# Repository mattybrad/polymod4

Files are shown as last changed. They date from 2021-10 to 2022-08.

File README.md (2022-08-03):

# PolyMod 4

A polyphonic digital synthesizer which can be patched like an analog modular synth.

Current setup is C++ code running on an Electrosmith Daisy board (with built-in DAC), on a PCB which includes potentiometers, buttons, LEDs, and circuitry to detect connections between output and input sockets.

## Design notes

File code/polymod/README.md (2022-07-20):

# test1

## Author

<!-- Insert Your Name Here -->

## Description

<!-- Describe your example here -->

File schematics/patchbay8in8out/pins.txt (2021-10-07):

Pins required to connect microcontroller (Teensy, Arduino, etc) to patchbay board:

(IN ORDER, TOP TO BOTTOM)
VCC (3.3V/5V)
Output data (arduino 2)
Output clock (arduino 3, etc)
Output latch
Input load
Input clock
Input clock enable
Input data (...arduino 8)
GND

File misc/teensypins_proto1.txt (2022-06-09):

Pins for PCB prototype 1.
Pins in round brackets are required by audio board.

0       MIDI input (6N138)
1       Utility 595 data
2       Patching 595 data
3       Patching 595 clock
4       Patching 595 latch
5       Utility 595 clock
6       Utility 595 latch
7       (Audio data) (N.B. ALSO PT8211 DIN)
8       (Audio data)
9       Patching 165 load
10      Patching 165 clock
11      Patching 165 clock enable
12      Patching 165 data

13      Basic LED
14  A0  4051 #1
15  A1  4051 #2
16  A2  4051 #3
17  A3  4051 #4
18  A4  (Audio control) (Display SDA)
19  A5  (Audio control) (Display SCL)
20  A6  (Audio data) (N.B. ALSO PT8211 WS)
21  A7  (Audio data) (N.B. ALSO PT8211 BCK)
22  A8  4051 #5 (buttons etc)
23  A9  (Audio data)

(Pins 24 onwards are Teensy 4.1 only, hence just for debugging/experimental stuff)
24  A10 MIDI output
25  A11 
26  A12 
27  A13 
28      
29      
30      
31      
32      

33      
34      
35      
36      
37      
38  A14 
39  A15 
40  A16 
41  A17 

This design doesn't make optimal use of all the pins, but is a good compromise to make coding a bit easier. I'm using two separate chains of 595s so that patching (which is already complex) doesn't get any harder. LEDs are driven by 595s, which is not ideal but just makes things easy rather than learning about LED driver ICs just for a prototype. Tactile buttons are running through a 5th 4051 because I'm already addressing the 4051 group so it means I don't have to add more 165s. 4051s are addressed by the 595s because of lack of pins. One pin was spare, hence using pin 13 as LED for debugging etc. A Teensy 4.1 can be connected for extra pins. I've included pin info for the PT8211 because this might be the chip in the final design rather than an audio adaptor board. Happily, the PT8211 only uses a subset of the audio shield's pins, so I can try swapping out the boards on the prototype without changing the PCB. LATEST UPDATE actually probably using PCM5102 instead. Not totally sure which pins it uses yet.

A more optimal design might be something like:

0       MIDI input (6N138)
1       LED driver?
2       595 data
3       595 clock
4       595 latch
5       LED driver?
6       LED driver?
7       (Audio data)
8       (Audio data)
9       165 load
10      165 clock
11      165 clock enable
12      165 data

13      LED driver?
14  A0  4051 #1
15  A1  4051 #2
16  A2  4051 #3
17  A3  4051 #4
18  A4  (Audio control)
19  A5  (Audio control)
20  A6  (Audio data)
21  A7  (Audio data)
22  A8  LED driver?
23  A9  (Audio data)

24  A10 
25  A11 
26  A12 
27  A13 
28      
29      
30      
31      
32      

33      
34      
35      
36      
37      
38  A14 
39  A15 
40  A16 
41  A17 

To drive LEDs and an OLED display, we could either route the 4051 outputs into an extra 4051, or just switch to Teensy 4.1. Other future considerations include CV in/out and SD card stuff.

PROBABLY ALLOW 4.1 TO BE CONNECTED TO PCB IF BOTH ARE INTERACHANGEABLE

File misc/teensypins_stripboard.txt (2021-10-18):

Pins for interim stripboard prototype.
Pins in round brackets are required by audio board.
Pins in square brackets likely to change for next version.

0       MIDI input
1
2       Patching 595 data
3       Patching 595 clock
4       Patching 595 latch
5
6
7       (Audio data)
8       (Audio data)
9       Patching 165 load
10      Patching 165 clock
11      Patching 165 clock enable
12      Patching 165 data

13
14  A0  [Pot 0]
15  A1  [Pot 1]
16  A2  [Pot 2]
17  A3  [Pot 3]
18  A4  (Audio control)
19  A5  (Audio control)
20  A6  (Audio data)
21  A7  (Audio data)
22  A8
23  A9  (Audio data)

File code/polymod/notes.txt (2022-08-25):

Have now got a working system, in mono at least.
A few next steps:
        Tidy up the source code, making it nicer to define sockets/modules
        Better pseudo connection system
    Also make pot definitions part of same slickening process
        InVal and OutVal might be unnecessary, could just use Val?
        Centralise sample rate, don't just hardcode 48000 each time
    Add some error catching stuff to prevent compilation of bad configurations
        Add logical pin ordering (0 at top, 31 at bottom)
    Optimise delays - system tick stuff is blocking? and delayMS is too coarse (callback system?)
    Smooth analog controls (sounds too "steppy")
        Add LFO module to help test filters etc
        Add polyphony (!!!)
    Add RPS module
    Add CPU monitoring
    Stress-test the code
    Fade in connections
        Fix bug where MIDI triggers on note off rather than note on sometimes
        Add better MIDI note handling, note off, note timestamps, etc
    Why does whole thing crash when filter receives LFO signal?!
    Values should default to zero (or some defined value) when not connected
    Bit crusher is doing something weird where it somehow removes polyphony from signal chain?!
    Plan/write patch save system (QSPI? SD? External EEPROM?)
    Try setting up some nice patches, e.g. krell, filtered noise
    Think of some cool poly-specific modules, e.g. harmoniser

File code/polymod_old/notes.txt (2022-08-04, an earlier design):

complex (proper?) way to do ordering:

on new connection/disconnection:

start at main output socket, give orderNum 0
list all source sockets
for each 0 source:
    give orderNum 1
    for each source:
        give orderNum 2

        etc

now give modules an order
for each module, scan all sockets to find highest orderNum
process all modules in descending orderNum order (highest first, ending with IO module)
(except IO module also has audio input! which might be the first thing in chain! oh no!)

---

maybe better to process sockets instead of modules
works as above but without needing to assign orderNums to modules
but will it work in practice..?
e.g.
square wave through filter, filter modulated by lfo:
    output 0
    filter out 1
    filter mod 2
    lfo out 3
    filter in 2
    square wave out 3

    so...

    process lfo out, osc.process()
    process square wave out, osc.process()
    process filter mod, out=lfo in
    process filter in, out=square in
    process filter out, set freq, filter.process(filter in)
    process output, out=filter in

or...
two vcos into a mixer
    output 0
    mixer out 1
    mixer in A 2
    mixer in B 2
    vco A out 3
    vco B out 3

    so...

    process vcos
    mixer ins pass through
    mixer out = sum of mixer ins

--------

might need to rewrite things with above in mind
need to be able to process sockets rather than modules
are modules even necessary, other than to keep things organised?
so, something like...
init modules
add pseudoConnections between input/output sockets within modules
make some physical connections
a connected input socket should have pointer to its source output socket
and/or a connected output socket should have a pointer to its destination input socket
(sockets generally become more complex/active classes)
start at IO output
figure out processing output order
process all sockets in order
this means that socket class will need a process() function
this should probably be defined in the module class, as a pointer?
so, in vco init, sockets[0].processFunction = &processSquareOut (?)
(some worries here about interdependent sockets, but can't quite think of a good problematic example)
output socket process will be something daisySP-ish, referencing various bits of a module
input socket process will be basically set socket outVal to value of source pointer
(hopefully don't need to redefine this behaviour for each input socket)

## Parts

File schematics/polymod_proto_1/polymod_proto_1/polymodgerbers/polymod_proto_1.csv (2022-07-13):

Comment | Designator | Footprint | LCSC
Device_Audio_Electrosmith_Daisy_Seed_Rev4 | A1 | Device_Audio_Electrosmith_Daisy_Seed:Device_Audio_Electrosmith_Daisy_Seed
470uF | C1 | Capacitor_THT:CP_Radial_D6.3mm_P2.50mm
1N4148 | D1 | Diode_SMD:D_SOD-123 | C81598
LED | D2,D3,D4,D5,D6 | LED_THT:LED_D5.0mm
1N4148 | D7,D8,D9,D10,D11,D12,D13,D14,D15,D16,D17,D18,D19,D20,D21,D22,D23,D24,D25,D26,D27,D28,D29,D30,D31,D32,D33,D34,D35,D36,D37,D38 | polymodcustom:Nexperia_CFP3_SOD-123W | C81598
MountingHole | H1,H2,H3,H4 | MountingHole:MountingHole_3.2mm_M3
Conn_01x02_Male | J1,J3 | Connector_PinHeader_2.54mm:PinHeader_1x02_P2.54mm_Vertical
Conn_01x03_Male | J2,J14 | Connector_PinHeader_2.54mm:PinHeader_1x03_P2.54mm_Vertical
Barrel_Jack | J4 | Connector_PinHeader_2.54mm:PinHeader_1x02_P2.54mm_Vertical
Conn_01x08_Male | J6,J7,J8,J9,J10,J11,J12,J13 | Connector_PinSocket_2.54mm:PinSocket_1x08_P2.54mm_Vertical
Jumper_2_Open | JP1 | Connector_PinHeader_2.54mm:PinHeader_1x02_P2.54mm_Vertical
220 | R1,R4,R5 | polymodcustom:R_0805_2012Metric | C17557
10K | R11,R12,R13,R14,R15,R16,R17,R18,R19,R20,R21,R22,R23,R24,R25,R26,R27,R28,R29,R30,R31,R32,R33,R34,R35,R36,R37,R38,R39,R40,R41,R42 | polymodcustom:R_0805_2012Metric | C17414
10k | R2 | polymodcustom:R_0805_2012Metric | C17414
470 | R3 | polymodcustom:R_0805_2012Metric | C17710
680R | R6,R7,R8,R9,R10 | polymodcustom:R_0805_2012Metric | C17798
R_Potentiometer | RV1,RV2,RV3,RV4,RV5,RV6,RV7,RV8,RV9,RV10,RV11,RV12,RV13,RV14,RV15,RV16 | polymodcustom:Potentiometer_Alps_RK09K_Single_Vertical
SW_Push | SW1,SW2,SW3,SW4 | polymodcustom:SW_PUSH-12mm
6N138 | U1 | Package_DIP:DIP-8_W7.62mm_Socket
74HC595 | U2,U5,U8,U9,U10 | Package_SO:SOIC-16_3.9x9.9mm_P1.27mm | C5947
74LS165 | U3,U6,U11,U12,U13 | Package_SO:SOIC-16_3.9x9.9mm_P1.27mm | C5613
4051 | U4,U7 | Package_SO:SOIC-16_3.9x9.9mm_P1.27mm | C21379

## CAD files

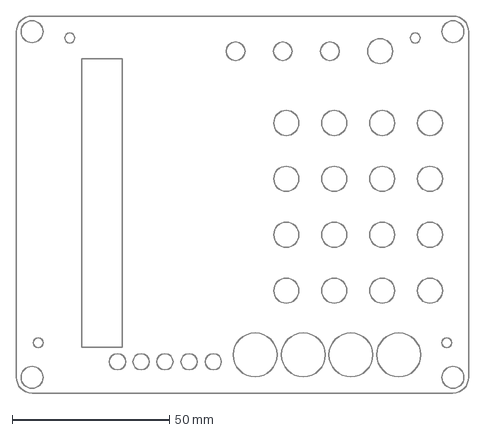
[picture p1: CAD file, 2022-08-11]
misc/lidcuts.svg.dxf
144.0 x 120.0 mm

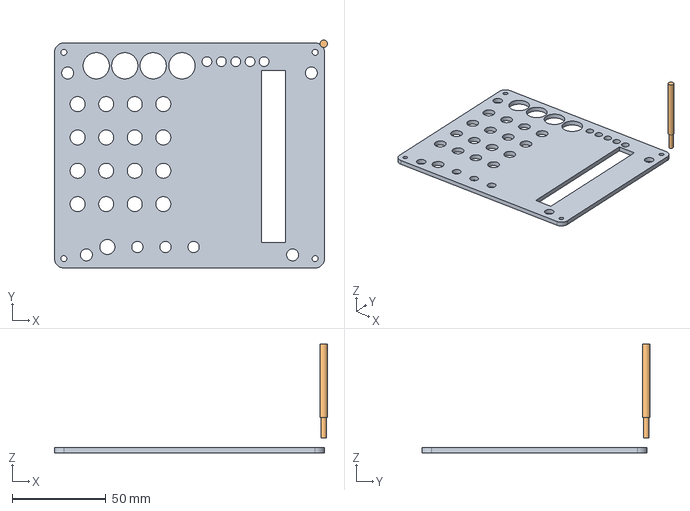
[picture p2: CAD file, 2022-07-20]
misc/morelidcutsedgeonly.FCStd
145.6 x 121.6 x 58.0 mm
CutTool

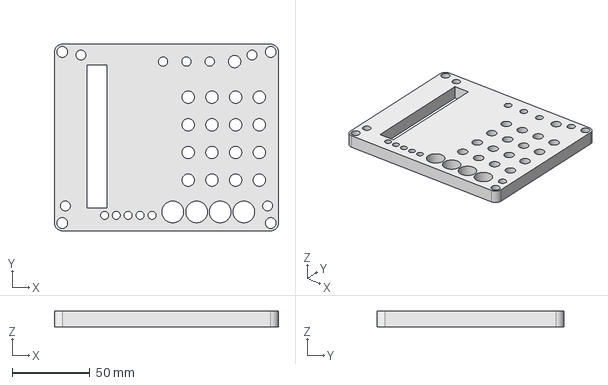
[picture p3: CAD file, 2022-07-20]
misc/lidcuts.FCStd
144.0 x 120.0 x 10.0 mm

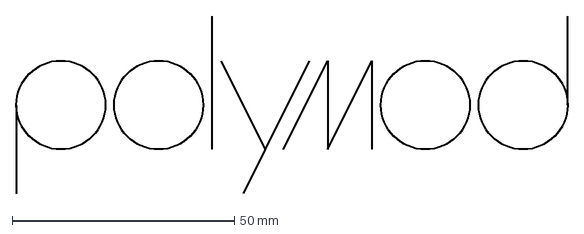
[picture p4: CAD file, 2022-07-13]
misc/polymodlogodxf.dxf
124.0 x 40.0 mm

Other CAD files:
misc/morelidcuts.FCStd

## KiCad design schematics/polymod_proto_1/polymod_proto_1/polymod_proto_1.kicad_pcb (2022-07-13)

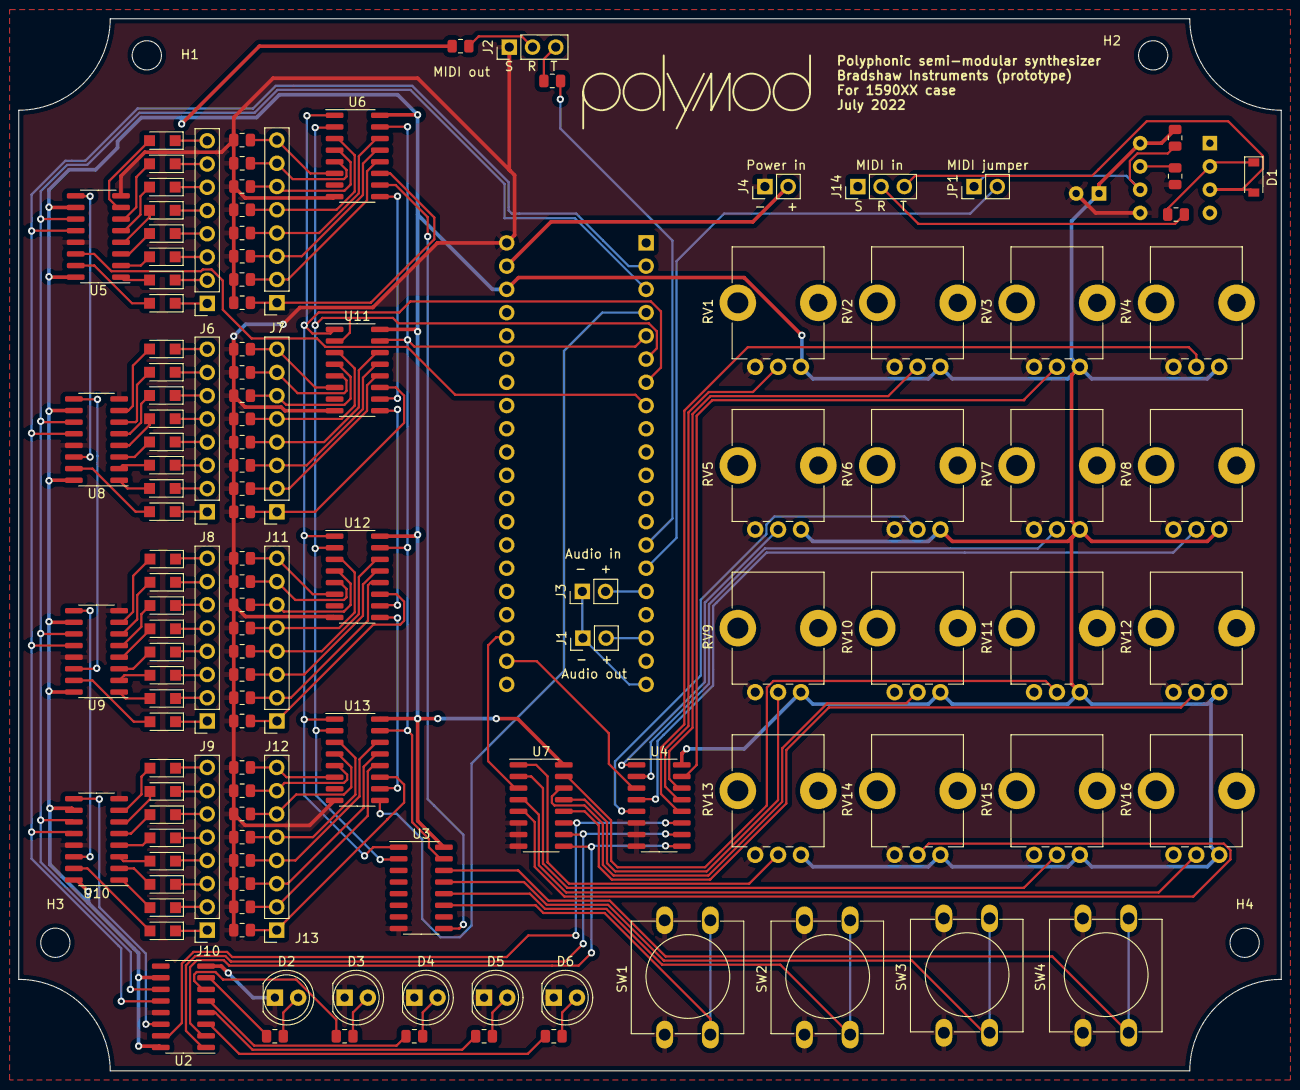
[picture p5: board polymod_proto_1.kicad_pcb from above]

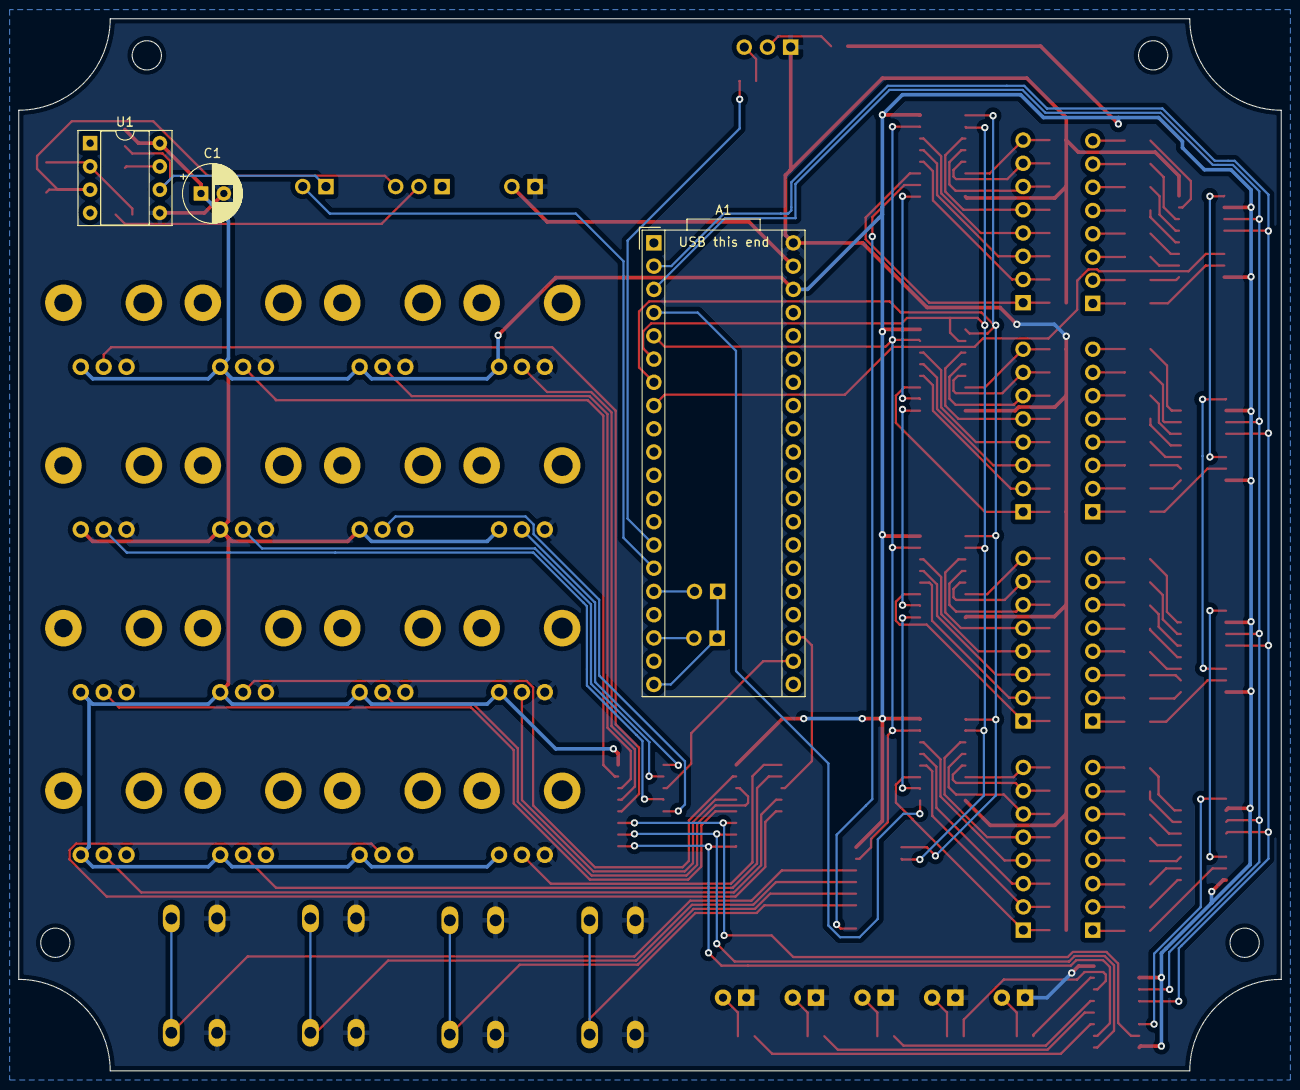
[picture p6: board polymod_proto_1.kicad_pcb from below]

Board: 2 copper layers, 138.0 x 115.0 mm, 133 parts (3 on the bottom side), 161 nets.

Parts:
A1: Device_Audio_Electrosmith_Daisy_Seed_Rev4; Device_Audio_Electrosmith_Daisy_Seed
C1: 470uF; CP_Radial_D6.3mm_P2.50mm
D1: 1N4148; D_SOD-123
D2, D3, D4, D5, D6: LED; LED_D5.0mm
D7, D8, D9, D10, D11, D12, D13, D14, D15, D16, D17, D18, D19, D20, D21, D22, D23, D24, D25, D26, D27, D28, D29, D30, D31, D32, D33, D34, D35, D36, D37, D38: 1N4148; Nexperia_CFP3_SOD-123W
H1, H2, H3, H4: MountingHole; MountingHole_3.2mm_M3
J1, J3: Conn_01x02_Male; PinHeader_1x02_P2.54mm_Vertical
J2, J14: Conn_01x03_Male; PinHeader_1x03_P2.54mm_Vertical
J4: Barrel_Jack; PinHeader_1x02_P2.54mm_Vertical
J6, J7, J8, J9, J10, J11, J12, J13: Conn_01x08_Male; PinSocket_1x08_P2.54mm_Vertical
JP1: Jumper_2_Open; PinHeader_1x02_P2.54mm_Vertical
R1, R4, R5: 220; R_0805_2012Metric
R2: 10k; R_0805_2012Metric
R3: 470; R_0805_2012Metric
R6, R7, R8, R9, R10: 680R; R_0805_2012Metric
R11, R12, R13, R14, R15, R16, R17, R18, R19, R20, R21, R22, R23, R24, R25, R26, R27, R28, R29, R30, R31, R32, R33, R34, R35, R36, R37, R38, R39, R40, R41, R42: 10K; R_0805_2012Metric
RV1, RV2, RV3, RV4, RV5, RV6, RV7, RV8, RV9, RV10, RV11, RV12, RV13, RV14, RV15, RV16: R_Potentiometer; Potentiometer_Alps_RK09K_Single_Vertical
SW1, SW2, SW3, SW4: SW_Push; SW_PUSH-12mm
U1: 6N138; DIP-8_W7.62mm_Socket
U2, U5, U8, U9, U10: 74HC595; SOIC-16_3.9x9.9mm_P1.27mm
U3, U6, U11, U12, U13: 74LS165; SOIC-16_3.9x9.9mm_P1.27mm
U4, U7: 4051; SOIC-16_3.9x9.9mm_P1.27mm

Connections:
4051_ADDRESS_A: U2.15 (QA), U4.11 (A), U7.11 (A)
4051_ADDRESS_B: U2.1 (QB), U4.10 (B), U7.10 (B)
4051_ADDRESS_C: U2.2 (QC), U4.9 (C), U7.9 (C)
/4051_1: A1.22 (ADC_INP10), U4.3 (X)
/4051_2: A1.23 (ADC_INP15), U7.3 (X)
/Input group 1/OUTPUT: U6.9 (Q7), U11.10 (DS)
/Input group 2/OUTPUT: U11.9 (Q7), U12.10 (DS)
/Input group 3/OUTPUT: U12.9 (Q7), U13.10 (DS)
/MIDI_IN: A1.15 (USART1_RX), JP1.2 (B)
/MIDI_OUT: A1.14 (USART1_TX), R5.2
/Output group 1/OUTPUT: U5.9 (QH'), U8.14 (SER)
/Output group 2/OUTPUT: U8.9 (QH'), U9.14 (SER)
/Output group 3/OUTPUT: U9.9 (QH'), U10.14 (SER)
/PATCHING_IN_DATA: A1.4 (SDMMC1_D1), U13.9 (Q7)
/PATCHING_OUT_DATA: A1.8 (SPI1_NSS), U5.14 (SER)
/UTIL_165: U3.9 (Q7), U6.10 (DS)
/UTIL_595: U2.14 (SER), U10.9 (QH')
/audio_in_tip: A1.16 (AUDIO_IN_L), J3.2
/audio_out_tip: A1.18 (AUDIO_OUT_L), J1.2
/midi_in_ring: J14.2, R1.2
/midi_in_tip: D1.2 (A), J14.3, U1.3 (C2)
/midi_out_ring: J2.2, R4.2
/midi_out_tip: J2.3, R5.1
GND: A1.40 (GND), C1.2, D2.1 (K), D3.1 (K), D4.1 (K), D5.1 (K), D6.1 (K), J2.1, J4.1, R2.1, R11.2, R12.2, R13.2, R14.2, R15.2, R16.2, R17.2, R18.2, R19.2, R20.2, R21.2, R22.2, R23.2, R24.2, R25.2, R26.2, R27.2, R28.2, R29.2, R30.2, R31.2, R32.2, R33.2, R34.2, R35.2, R36.2, R37.2, R38.2, R39.2, R40.2, R41.2, R42.2, RV1.3, RV2.3, RV3.3, RV4.3, RV5.3, RV6.3, RV7.3, RV8.3, RV9.3, RV10.3, RV11.3, RV12.3, RV13.3, RV14.3, RV15.3, RV16.3, SW1.1, SW2.1, SW3.1, SW4.1, U1.5 (GND), U2.8 (GND), U2.13 (~OE), U3.8 (GND), U4.6 (Inh), U4.7 (VEE), U4.8 (VSS), U5.8 (GND), U5.13 (~OE), U6.8 (GND), U7.6 (Inh), U7.7 (VEE), U7.8 (VSS), U8.8 (GND), U8.13 (~OE), U9.8 (GND), U9.13 (~OE), U10.8 (GND), U10.13 (~OE), U11.8 (GND), U12.8 (GND), U13.8 (GND)
GNDA: A1.20 (AGND), J1.1, J3.1
unnamed: A1.39 (VIN), J4.2
unnamed: D1.1 (K), R1.1, U1.2 (C1)
unnamed: D2.2 (A), R6.2
unnamed: D3.2 (A), R7.2
unnamed: D4.2 (A), R8.2
unnamed: D5.2 (A), R9.2
unnamed: D6.2 (A), R10.2
unnamed: D7.1 (K), J6.1
unnamed: D7.2 (A), U5.15 (QA)
unnamed: D8.1 (K), J6.2
unnamed: D8.2 (A), U5.1 (QB)
unnamed: D9.1 (K), J6.3
unnamed: D9.2 (A), U5.2 (QC)
unnamed: D10.1 (K), J6.4
unnamed: D10.2 (A), U5.3 (QD)
unnamed: D11.1 (K), J6.5
unnamed: D11.2 (A), U5.4 (QE)
unnamed: D12.1 (K), J6.6
unnamed: D12.2 (A), U5.5 (QF)
unnamed: D13.1 (K), J6.7
unnamed: D13.2 (A), U5.6 (QG)
unnamed: D14.1 (K), J6.8
unnamed: D14.2 (A), U5.7 (QH)
unnamed: D15.1 (K), J8.1
unnamed: D15.2 (A), U8.15 (QA)
unnamed: D16.1 (K), J8.2
unnamed: D16.2 (A), U8.1 (QB)
unnamed: D17.1 (K), J8.3
unnamed: D17.2 (A), U8.2 (QC)
unnamed: D18.1 (K), J8.4
unnamed: D18.2 (A), U8.3 (QD)
unnamed: D19.1 (K), J8.5
unnamed: D19.2 (A), U8.4 (QE)
unnamed: D20.1 (K), J8.6
unnamed: D20.2 (A), U8.5 (QF)
unnamed: D21.1 (K), J8.7
unnamed: D21.2 (A), U8.6 (QG)
unnamed: D22.1 (K), J8.8
unnamed: D22.2 (A), U8.7 (QH)
unnamed: D23.1 (K), J9.1
unnamed: D23.2 (A), U9.15 (QA)
unnamed: D24.1 (K), J9.2
unnamed: D24.2 (A), U9.1 (QB)
unnamed: D25.1 (K), J9.3
unnamed: D25.2 (A), U9.2 (QC)
unnamed: D26.1 (K), J9.4
unnamed: D26.2 (A), U9.3 (QD)
unnamed: D27.1 (K), J9.5
unnamed: D27.2 (A), U9.4 (QE)
unnamed: D28.1 (K), J9.6
unnamed: D28.2 (A), U9.5 (QF)
unnamed: D29.1 (K), J9.7
unnamed: D29.2 (A), U9.6 (QG)
unnamed: D30.1 (K), J9.8
unnamed: D30.2 (A), U9.7 (QH)
unnamed: D31.1 (K), J10.1
unnamed: D31.2 (A), U10.15 (QA)
unnamed: D32.1 (K), J10.2
unnamed: D32.2 (A), U10.1 (QB)
unnamed: D33.1 (K), J10.3
unnamed: D33.2 (A), U10.2 (QC)
unnamed: D34.1 (K), J10.4
unnamed: D34.2 (A), U10.3 (QD)
unnamed: D35.1 (K), J10.5
unnamed: D35.2 (A), U10.4 (QE)
unnamed: D36.1 (K), J10.6
unnamed: D36.2 (A), U10.5 (QF)
unnamed: D37.1 (K), J10.7
unnamed: D37.2 (A), U10.6 (QG)
unnamed: D38.1 (K), J10.8
unnamed: D38.2 (A), U10.7 (QH)
unnamed: J7.1, R17.1, U6.11 (D0)
unnamed: J7.2, R15.1, U6.12 (D1)
unnamed: J7.3, R13.1, U6.13 (D2)
unnamed: J7.4, R11.1, U6.14 (D3)
unnamed: J7.5, R18.1, U6.3 (D4)
unnamed: J7.6, R16.1, U6.4 (D5)
unnamed: J7.7, R14.1, U6.5 (D6)
unnamed: J7.8, R12.1, U6.6 (D7)
unnamed: J11.1, R25.1, U11.11 (D0)
unnamed: J11.2, R23.1, U11.12 (D1)
unnamed: J11.3, R21.1, U11.13 (D2)
unnamed: J11.4, R19.1, U11.14 (D3)
unnamed: J11.5, R26.1, U11.3 (D4)
unnamed: J11.6, R24.1, U11.4 (D5)
unnamed: J11.7, R22.1, U11.5 (D6)
unnamed: J11.8, R20.1, U11.6 (D7)
unnamed: J12.1, R33.1, U12.11 (D0)
unnamed: J12.2, R31.1, U12.12 (D1)
unnamed: J12.3, R29.1, U12.13 (D2)
unnamed: J12.4, R27.1, U12.14 (D3)
unnamed: J12.5, R34.1, U12.3 (D4)
unnamed: J12.6, R32.1, U12.4 (D5)
unnamed: J12.7, R30.1, U12.5 (D6)
unnamed: J12.8, R28.1, U12.6 (D7)
unnamed: J13.1, R41.1, U13.11 (D0)
unnamed: J13.2, R39.1, U13.12 (D1)
unnamed: J13.3, R37.1, U13.13 (D2)
unnamed: J13.4, R35.1, U13.14 (D3)
unnamed: J13.5, R42.1, U13.3 (D4)
unnamed: J13.6, R40.1, U13.4 (D5)
unnamed: J13.7, R38.1, U13.5 (D6)
unnamed: J13.8, R36.1, U13.6 (D7)
unnamed: JP1.1 (A), R3.2, U1.6 (VO2)
unnamed: R2.2, U1.7 (VO1)
unnamed: R6.1, U2.7 (QH)
unnamed: R7.1, U2.6 (QG)
unnamed: R8.1, U2.5 (QF)
unnamed: R9.1, U2.4 (QE)
unnamed: R10.1, U2.3 (QD)
unnamed: RV1.2, U4.13 (X0)
unnamed: RV2.2, U4.14 (X1)
unnamed: RV3.2, U4.15 (X2)
unnamed: RV4.2, U4.12 (X3)
unnamed: RV5.2, U4.1 (X4)
unnamed: RV6.2, U4.5 (X5)
unnamed: RV7.2, U4.2 (X6)
unnamed: RV8.2, U4.4 (X7)
unnamed: RV9.2, U7.13 (X0)
unnamed: RV10.2, U7.14 (X1)
unnamed: RV11.2, U7.15 (X2)
unnamed: RV12.2, U7.12 (X3)
unnamed: RV13.2, U7.1 (X4)
unnamed: RV14.2, U7.5 (X5)
unnamed: RV15.2, U7.2 (X6)
unnamed: RV16.2, U7.4 (X7)
unnamed: SW1.2, U3.11 (D0)
unnamed: SW2.2, U3.12 (D1)
unnamed: SW3.2, U3.13 (D2)
unnamed: SW4.2, U3.14 (D3)
PATCHING_IN_CE: A1.5 (SDMMC1_D0), U3.15 (~CE), U6.15 (~CE), U11.15 (~CE), U12.15 (~CE), U13.15 (~CE)
PATCHING_IN_CLOCK: A1.6 (SDMMC1_CMD), U3.2 (CP), U6.2 (CP), U11.2 (CP), U12.2 (CP), U13.2 (CP)
PATCHING_IN_LOAD: A1.7 (SDMMC1_CK), U3.1 (~PL), U6.1 (~PL), U11.1 (~PL), U12.1 (~PL), U13.1 (~PL)
PATCHING_OUT_CLOCK: A1.3 (SDMMC1_D2), U2.11 (SRCLK), U5.11 (SRCLK), U8.11 (SRCLK), U9.11 (SRCLK), U10.11 (SRCLK)
PATCHING_OUT_LATCH: A1.2 (SDMMC1_D3), U2.12 (RCLK), U5.12 (RCLK), U8.12 (RCLK), U9.12 (RCLK), U10.12 (RCLK)
VCC: A1.38 (3V3_D), C1.1, R3.1, R4.1, RV1.1, RV2.1, RV3.1, RV4.1, RV5.1, RV6.1, RV7.1, RV8.1, RV9.1, RV10.1, RV11.1, RV12.1, RV13.1, RV14.1, RV15.1, RV16.1, U1.8 (VCC), U2.10 (~SRCLR), U2.16 (VCC), U3.16 (VCC), U4.16 (VDD), U5.10 (~SRCLR), U5.16 (VCC), U6.16 (VCC), U7.16 (VDD), U8.10 (~SRCLR), U8.16 (VCC), U9.10 (~SRCLR), U9.16 (VCC), U10.10 (~SRCLR), U10.16 (VCC), U11.16 (VCC), U12.16 (VCC), U13.16 (VCC)

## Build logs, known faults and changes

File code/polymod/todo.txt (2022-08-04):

Make pin ordering logical (0 at top, 31 at bottom)
Use pots
Add all modules to central list
Centralise sample rate, don't just hardcode 48000 each time
Initialise vector members as null
Smooth analog controls (sounds too "steppy")
Optimise delays - system tick stuff is blocking? and delayMS is too coarse

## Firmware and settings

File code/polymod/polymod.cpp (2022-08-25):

// functions borrowed from Arduino source code to help bit manipulation (for addressing 4051s, etc)
#define bitRead(value, bit) (((value) >> (bit)) & 0x01)
#define bitSet(value, bit) ((value) |= (1UL << (bit)))
#define bitClear(value, bit) ((value) &= ~(1UL << (bit)))
#define bitWrite(value, bit, bitvalue) (bitvalue ? bitSet(value, bit) : bitClear(value, bit))

// include libraries
#include "daisy_seed.h"
#include "daisysp.h"
#include "core_cm7.h"
#include "sr_165.h"

//using namespace daisy;
using namespace daisy::seed;

#include "Connection.h" 
#include "Socket.h"

// include modules
#include "modules/Module.h"
#include "modules/VCO.h"
#include "modules/VCF.h"
#include "modules/VCA.h"
#include "modules/LFO.h"
#include "modules/BitCrusher.h"
#include "modules/Envelope.h"
#include "modules/Mult.h"
#include "modules/Mixer.h"
#include "modules/Noise.h"
#include "modules/IO.h"

// socket stuff
Socket sockets[64];
Socket *socketOrder[64];
const int MAX_CONNECTIONS = 32;
Connection connections[MAX_CONNECTIONS];

// debugging stuff
bool useSerial = false;

// define chain of 5 74hc165 shift registers (read many digital inputs)
using My165Chain = ShiftRegister165<5>;
ShiftRegister595 outputChain;
My165Chain inputChain;

// patching variables
uint8_t inputReadings[32];
uint8_t prevInputReadings[32];
uint8_t stableCycles[32];
uint8_t stableInputReadings[32];
int bitNumber = 0;

// analog variables
float analogReadings[16];
float *knobParams[16];
int analogChannel = 0;

DaisySeed hw;
MidiUartHandler midi;

// declare modules
VCO vco1;
VCO vco2;
LFO lfo;
VCF vcf;
VCA vca;
BitCrusher crusher;
Envelope env1;
Envelope env2;
Mult mult;
Mixer mixer;
Noise noise;
IO io;

// declare functions
void addConnection(uint8_t physicalOutputNum, uint8_t physicalInputNum);
void removeConnection(uint8_t physicalOutputNum, uint8_t physicalInputNum);
void calculateSocketOrder();
void setSocketOrder(Socket *socket, int order);
void initKnob(int knobNum, float *param);
void initOutput(int socketNumber, Module *module, int param);
void initInput(int socketNumber, Module *module, int param);
int getSystemPinNum(int userPinNum);
void handlePhysicalConnections();

float dummyFloat;
void AudioCallback(AudioHandle::InputBuffer in, AudioHandle::OutputBuffer out, size_t size)
{
	for (size_t i = 0; i < size; i++)
	{
		io.mainInputValue = in[0][i];
		bool nullFound = false;
		for (int j = 0; j < 64 && !nullFound; j++)
		{
			if(socketOrder[j] == nullptr) {
				nullFound = true;
			} else {
				socketOrder[j]->process(i);
			}
		}

		// set daisy seed output as final stage (IO module) output
		float finalOutput = 0.0f;
		for(int j=0; j<Module::MAX_POLYPHONY; j++) {
			finalOutput += io.sockets[IO::MAIN_OUTPUT_IN]->value[j];
		}
		finalOutput = 0.1 * finalOutput;
		out[0][i] = finalOutput;
		out[1][i] = finalOutput;
	}
}

int main(void)
{
	// Daisy Seed config
	hw.Configure();
	hw.Init();
	hw.SetAudioBlockSize(8); // can increase this if having performance issues
	hw.SetAudioSampleRate(SaiHandle::Config::SampleRate::SAI_48KHZ);

	// Polymod hardware config
	My165Chain::Config inputChainConfig;
	inputChainConfig.clk = D5;
	inputChainConfig.latch = D6;
	inputChainConfig.data[0] = D3;
	inputChain.Init(inputChainConfig);
	dsy_gpio_pin outputChainPins[3] = {D1, D2, D7};
	outputChain.Init(outputChainPins, 5);
	GPIO inputChainClockEnable;
	inputChainClockEnable.Init(D4, GPIO::Mode::OUTPUT);
	inputChainClockEnable.Write(false);
	AdcChannelConfig analogInputs[2];
	analogInputs[0].InitSingle(A0);
	analogInputs[1].InitSingle(A1);
	hw.adc.Init(analogInputs, 2);
	hw.adc.Start();

	MidiUartHandler::Config midiConfig;
	midiConfig.transport_config.rx = D14;
	midiConfig.transport_config.tx = D13;
	midi.Init(midiConfig);
	midi.StartReceive();

	// start serial log (wait for connection)
	if (useSerial)
	{
		hw.StartLog(true);
		hw.PrintLine("STARTED POLYMOD :)");
	}

	hw.StartAudio(AudioCallback);

	// set up sockets
	for(int i=0; i<64; i++) {
		sockets[i].socketNum = i;
	}
	initOutput(0, &vco1, VCO::AUDIO_OUT);
	initOutput(1, &vcf, VCF::LPF_OUT);
	initOutput(2, &lfo, LFO::CONTROL_OUT);
	initOutput(3, &crusher, BitCrusher::AUDIO_OUT);
	initOutput(4, &io, IO::MIDI_PITCH);
	initOutput(5, &io, IO::MIDI_GATE);
	initOutput(6, &vca, VCA::AUDIO_OUT);
	initOutput(7, &env1, Envelope::CONTROL_OUT);

	initOutput(8, &mult, Mult::OUTPUT_1);
	initOutput(9, &mult, Mult::OUTPUT_2);
	initOutput(10, &noise, Noise::WHITE_NOISE_OUT);
	initOutput(11, &mixer, Mixer::OUTPUT);
	initOutput(12, &env2, Envelope::CONTROL_OUT);
	initOutput(13, &io, IO::MAIN_INPUT_OUT);

	initInput(32, &io, IO::MAIN_OUTPUT_IN);
	initInput(33, &vcf, VCF::AUDIO_IN);
	initInput(34, &vcf, VCF::FREQ_IN);
	initInput(35, &vco1, VCO::FREQ_IN);
	initInput(36, &crusher, BitCrusher::AUDIO_IN);
	initInput(37, &vca, VCA::AUDIO_IN);
	initInput(38, &vca, VCA::CONTROL_IN);
	initInput(39, &env1, Envelope::GATE_IN);

	initInput(40, &mult, Mult::INPUT);
	initInput(41, &mixer, Mixer::INPUT_1);
	initInput(42, &mixer, Mixer::INPUT_2);
	initInput(43, &env2, Envelope::GATE_IN);
	
	// set up knobs
	for(int i=0; i<16; i++) {
		knobParams[i] = nullptr;
	}

	initKnob(0, &vco1.freqControl);
	initKnob(1, &vcf.cutoffControl);
	initKnob(2, &vcf.resControl);
	initKnob(3, &lfo.freqControl);

	initKnob(4, &env1.attackControl);
	initKnob(5, &env1.decayControl);
	initKnob(6, &env1.sustainControl);
	initKnob(7, &env1.releaseControl);

	initKnob(8, &env2.attackControl);
	initKnob(9, &env2.decayControl);
	initKnob(10, &env2.sustainControl);
	initKnob(11, &env2.releaseControl);

	// temp connections
	bool useTempConnections = false;
	if(useTempConnections) {
		// "full" synth voice with separate filter/amp envelopes
		addConnection(0, 33);
		addConnection(1, 37);
		addConnection(6, 32);
		addConnection(4, 35);
		addConnection(5, 40);
		addConnection(8, 39);
		addConnection(9, 43);
		addConnection(7, 34);
		addConnection(12, 38);
	}

	for (int i = 0; i < Module::MAX_POLYPHONY; i++)
	{
		env1.adsr[i].SetTime(ADSR_SEG_ATTACK, 2);
		env1.adsr[i].SetTime(ADSR_SEG_DECAY, 2);
		env1.adsr[i].SetTime(ADSR_SEG_RELEASE, 1.0);
		env1.adsr[i].SetSustainLevel(.5);
	}

	// main loop, everything happens in here
	while (1)
	{
		// do nothing here for now, this is where all the shift reg stuff goes
		handlePhysicalConnections();
	}
}

uint8_t findFreeConnectionSlot()
{
	bool foundSlot = false;
	uint8_t slotNum = 0;
	for (uint8_t i = 0; i < MAX_CONNECTIONS && !foundSlot; i++)
	{
		if (!connections[i].isConnected)
		{
			slotNum = i;
			foundSlot = true;
		}
	}
	return slotNum; // should probably check all slots aren't full...
}

void addConnection(uint8_t physicalOutputNum, uint8_t physicalInputNum)
{
	uint8_t slotNum = findFreeConnectionSlot();
	if (useSerial)
	{
		hw.PrintLine("Connection slot %d", slotNum);
	}
	connections[slotNum].isConnected = true;
	connections[slotNum].physicalOutputNum = physicalOutputNum;
	connections[slotNum].physicalInputNum = physicalInputNum;
	sockets[physicalOutputNum].destSocket = &sockets[physicalInputNum];
	sockets[physicalInputNum].sourceSocket = &sockets[physicalOutputNum];
	calculateSocketOrder();
}

void removeConnection(uint8_t physicalOutputNum, uint8_t physicalInputNum)
{
	for (uint8_t i = 0; i < MAX_CONNECTIONS; i++)
	{
		if (connections[i].isConnected && connections[i].physicalOutputNum == physicalOutputNum && connections[i].physicalInputNum == physicalInputNum)
		{
			connections[i].isConnected = false;
			sockets[physicalOutputNum].destSocket = nullptr;
			sockets[physicalInputNum].sourceSocket = nullptr;
			if (useSerial)
				hw.PrintLine("Removed connection %d", i);
		}
	}
	calculateSocketOrder();
}

void calculateSocketOrder() {

	// reset order numbers
	for (int i = 0; i < 64; i++)
	{
		sockets[i].order = -1;
		sockets[i].orderSet = false;
	}

	// start at IO output (input socket)
	setSocketOrder(io.sockets[IO::MAIN_OUTPUT_IN], 0); // recursive function, sets order number for all sockets
	// after this, sockets should have higher order numbers as they get further away from end of signal chain

	// reset socket order
	for (int i = 0; i < 64; i++)
	{
		socketOrder[i] = nullptr;
	}

	int orderIndex = 0; // this number is HIGHEST at end of signal chain (opposite of above)

	// start at 64, maximum possible order number (?)
	for (int i = 64; i >= 0; i--)
	{
		// for each socket...
		for (int j = 0; j < 64; j++)
		{
			if (sockets[j].order == i)
			{
				socketOrder[orderIndex] = &sockets[j];
				orderIndex++;
			}
		}
	}

	if (useSerial)
	{
		hw.Print("Socket order: ");
		bool nullFound = false;
		for (int i = 0; i < 64 && !nullFound; i++)
		{
			if(socketOrder[i] == nullptr) nullFound = true;
			else {
				hw.Print("%d ", socketOrder[i]->socketNum);
			}
		}
		hw.Print("\n");
	}
}

void setSocketOrder(Socket *socket, int order)
{
	if (!socket->orderSet)
	{
		socket->order = order;
		socket->orderSet = true;
		if (socket->socketType == Socket::INPUT)
		{
			if (socket->sourceSocket != nullptr)
			{
				setSocketOrder(socket->sourceSocket, order + 1);
			}
		}
		else if (socket->socketType == Socket::OUTPUT)
		{
			for (int i = 0; i < socket->module->numPseudoSources; i++)
			{
				if (socket->module->pseudoSources[i][1] == socket->param)
				{
					// pseudo socket destination matches output
					setSocketOrder(socket->module->sockets[socket->module->pseudoSources[i][0]], order + 1);
				}
			}
		}
	}
}

int getSystemPinNum(int userPinNum)
{
	return 8 * (userPinNum / 8) + 7 - (userPinNum % 8);
}

void initKnob(int knobNum, float *param) {
	knobParams[knobNum] = param;
}

void initOutput(int socketNumber, Module *module, int param)
{
	//int systemSocketNumber = getSystemPinNum(socketNumber); // remap
	sockets[socketNumber].socketType = Socket::OUTPUT;
	sockets[socketNumber].module = module;
	sockets[socketNumber].param = param;
	module->sockets[param] = &sockets[socketNumber];
}

void initInput(int socketNumber, Module *module, int param)
{
	//int systemSocketNumber = getSystemPinNum(socketNumber); // remap
	sockets[socketNumber].socketType = Socket::INPUT;
	sockets[socketNumber].module = module;
	sockets[socketNumber].param = param;
	module->sockets[param] = &sockets[socketNumber];
}

void handlePhysicalConnections() {
	// set output bits for patching output channels
	for (int i = 0; i < 32; i++)
	{
		outputChain.Set(i, bitRead(i + 1, bitNumber));
	}

	// set bits to address 4051s
	outputChain.Set(32, bitRead(analogChannel, 0));
	outputChain.Set(33, bitRead(analogChannel, 1));
	outputChain.Set(34, bitRead(analogChannel, 2));

	// set LEDs
	for (int i = 0; i < 5; i++)
	{
		outputChain.Set(35 + i, analogReadings[0] > ((float)i + 0.5) / 5.0);
	}

	// read/write from/to shift registers
	outputChain.Write();
	inputChain.Update();

	for (int i = 0; i < 32; i++)
	{
		bitWrite(inputReadings[i], bitNumber, inputChain.State(i + 8));
	}
	if (bitNumber == 7)
	{
		for (int i = 0; i < 32; i++)
		{
			if (inputReadings[i] != prevInputReadings[i])
			{
				// change detected
				stableCycles[i] = 0;
			}
			else
			{
				if (stableCycles[i] < 3)
					stableCycles[i]++;
			}
			if (stableCycles[i] == 2)
			{
				if (inputReadings[i] > 0)
				{
					// connection
					if (useSerial)
						hw.Print("%d--->%d\n", inputReadings[i] - 1, i);
					//addConnection(inputReadings[i] - 1, i + 32);
					addConnection(getSystemPinNum(inputReadings[i] - 1), getSystemPinNum(i + 32));
				}
				else if (stableInputReadings[i] > 0)
				{
					// disconnection
					if (useSerial)
						hw.Print("%d-x->%d\n", stableInputReadings[i] - 1, i);
					//removeConnection(stableInputReadings[i] - 1, i + 32);
					removeConnection(getSystemPinNum(stableInputReadings[i] - 1), getSystemPinNum(i + 32));
				}
				stableInputReadings[i] = inputReadings[i];
			}
			prevInputReadings[i] = inputReadings[i];
		}
	}

	// midi stuff here just temporarily
	midi.Listen();
	// Handle MIDI Events
	while (midi.HasEvents())
	{
		io.handleMidiMessage(midi.PopEvent());
	}

	System::DelayUs(250); // seems to be required for 4051s to work properly - ideally replace blocking delay with callback
	analogReadings[analogChannel] = hw.adc.GetFloat(0);
	analogReadings[analogChannel + 8] = hw.adc.GetFloat(1);

	// temporarily handling knobs here
	for(int i=0; i<16; i++) {
		if(knobParams[i] != nullptr) {
			*knobParams[i] = analogReadings[i];
		}
	}

	analogChannel++; // probably merge analog channel and bitNumber, they're basically the same
	bitNumber = (bitNumber + 1) % 8;
	if (analogChannel == 8)
	{
		analogChannel = 0;
	}
}

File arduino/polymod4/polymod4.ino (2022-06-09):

// prototype monophonic implementation of polymod system
// 2 output registers, 2 input registers, 4 potentiometers

#include "Patchbay.h"

#include <Audio.h>
#include <Wire.h>
#include <SPI.h>
#include <SD.h>
#include <SerialFlash.h>
#include <MIDI.h>

AudioControlSGTL5000 sgtl5000_1;

#include "ModuleSine.h"
#include "ModuleVCO.h"
#include "ModuleVCF.h"
#include "ModuleVCA.h"
#include "ModuleADSR.h"
#include "ModuleMixer.h"
#include "ModuleMult.h"
#include "ModulePolySource.h"
#include "ModuleMidi.h"
#include "ModuleMain.h"
#include "SocketConnection.h"
#include "Globals.h"

#define NUM_OUTPUT_REGISTERS 2
#define NUM_INPUT_REGISTERS 2
const byte NUM_OUTPUT_CHANNELS = 8 * NUM_OUTPUT_REGISTERS;
const byte NUM_INPUT_CHANNELS = 8 * NUM_INPUT_REGISTERS;

Patchbay p(NUM_OUTPUT_REGISTERS,NUM_INPUT_REGISTERS,2,3,4,9,10,11,12);

ModuleSine moduleSine;
ModuleVCO moduleVCO;
ModuleVCO moduleVCO2;
ModuleVCF moduleVCF;
ModuleVCA moduleVCA;
ModuleADSR moduleADSR;
ModuleADSR moduleADSR2;
ModuleMixer moduleMixer;
ModuleMult moduleMult;
ModulePolySource modulePolySource;
ModuleMidi moduleMidi;
ModuleMain moduleMain;
SocketConnection connections[MAX_CONNECTIONS];
byte connectionIndex = 0;
SocketConnection *mainConnection = NULL;

SocketOutput *socketOutputs[NUM_OUTPUT_CHANNELS];
SocketInput *socketInputs[NUM_INPUT_CHANNELS];

void setup() {
  Serial.begin(9600);
  Serial.println("polymod 4 v1");

  usbMIDI.setHandleNoteOn(midiNoteOn);
  usbMIDI.setHandleNoteOff(midiNoteOff);

  // initialise teensy audio hardware
  AudioMemory(1000); // tweak this number for performance
  sgtl5000_1.enable();
  sgtl5000_1.volume(0.4);

  // initialise all socket pointers as null
  for(byte i=0; i<NUM_OUTPUT_CHANNELS; i++) {
    socketOutputs[i] = NULL;
  }
  for(byte i=0; i<NUM_INPUT_CHANNELS; i++) {
    socketInputs[i] = NULL;
  }

  // set references to individual sockets
  socketOutputs[0] = &moduleSine.audioOut;
  socketOutputs[1] = &moduleVCO.audioOut;
  socketOutputs[2] = &moduleVCO2.audioOut;
  socketOutputs[3] = &moduleMixer.audioOut;
  socketOutputs[4] = &modulePolySource.audioOut;
  socketOutputs[5] = &moduleVCF.audioOut;
  socketOutputs[6] = &moduleMidi.freqOut;
  socketOutputs[7] = &moduleMidi.gateOut;
  socketOutputs[8] = &moduleVCA.audioOut;
  socketOutputs[9] = &moduleADSR.controlOut;
  socketOutputs[10] = &moduleMult.out1;
  socketOutputs[11] = &moduleMult.out2;
  socketOutputs[12] = &moduleADSR2.controlOut;

  socketInputs[0] = &moduleMain.audioIn;
  socketInputs[1] = &moduleVCO.freqModIn;
  socketInputs[2] = &moduleVCO2.freqModIn;
  socketInputs[3] = &moduleMixer.audioIn1;
  socketInputs[4] = &moduleMixer.audioIn2;
  socketInputs[5] = &moduleVCF.audioIn;
  socketInputs[6] = &moduleVCF.freqModIn;
  socketInputs[7] = &moduleVCA.audioIn;
  socketInputs[8] = &moduleVCA.controlIn;
  socketInputs[9] = &moduleADSR.gateIn;
  socketInputs[10] = &moduleMult.in;
  socketInputs[11] = &moduleADSR2.gateIn;

  // set analog pins
  moduleVCO.analogPin = 17;
  moduleVCO2.analogPin = 16;

  // initialise patchbay
  p.begin();
  p.setCallbacks(handleConnection, handleDisconnection);

  // optional stress test for connections/disconnections:
  if(false) {
    for(unsigned int i=0; i<50000; i++) {
      handleConnection(1,0);
      if(i%1000 == 0) delay(100);
      handleDisconnection(1,0);
      if(i%1000 == 0) delay(100);
    }
    Serial.println("stress test success");
  }

  // optionally manually set patching

  handleConnection(6,1);
  handleConnection(12,6);
  handleConnection(7,10);
  handleConnection(10,9);
  handleConnection(11,11);
  handleConnection(9,8);
  handleConnection(1,7);
  handleConnection(8,5);
  handleConnection(5,0);

  moduleADSR2.tempChangeSettings();
}

// temp?
unsigned long nextCpuCheck = 0;
bool toggleTempConn = false;

void loop() {
  usbMIDI.read();
  p.update(); // need to remove delays from this function to speed up loop
  moduleVCO.update();
  moduleVCO2.update();
  moduleVCF.update();
  moduleADSR.update();
  moduleADSR2.update();

  if(nextCpuCheck<=millis() && false) {
    Serial.print("CPU usage = ");
    Serial.print(AudioProcessorUsage());
    Serial.print(", max = ");
    Serial.println(AudioProcessorUsageMax());
    Serial.print("Memory usage = ");
    Serial.print(AudioMemoryUsage());
    Serial.print(", max = ");
    Serial.println(AudioMemoryUsageMax());
    /*if(!toggleTempConn) {
      Serial.println("CONNECT TEMP");
      handleConnection(4,1);
    } else {
      Serial.println("DISCONNECT TEMP");
      handleDisconnection(4,1);
    }*/
    toggleTempConn = !toggleTempConn;
    nextCpuCheck += 5000;
  }
}

void handleConnection(unsigned int outNum, unsigned int inNum) {
  Serial.print("output ");
  Serial.print(outNum);
  Serial.print(" connected to input ");
  Serial.print(inNum);

  unsigned int i;
  bool foundAvailableConnection = false;
  // naive/slow - should probably start at last disconnection index..?
  for(i=0; i<MAX_CONNECTIONS && !foundAvailableConnection; i++) {
    if(!connections[i].inUse) {
      connections[i].connect(outNum, *socketOutputs[outNum], inNum, *socketInputs[inNum], i);
      if(inNum==0) {
        mainConnection = &connections[i];
      }
      Serial.print(", connection ");
      Serial.print(i);
      foundAvailableConnection = true;
    }
  }
  if(!foundAvailableConnection) Serial.print("RAN OUT OF CONNECTIONS");
  Serial.print("\n");
  calculatePolyStatuses();
}

void handleDisconnection(unsigned int outNum, unsigned int inNum) {
  Serial.print("output ");
  Serial.print(outNum);
  Serial.print(" disconnected from input ");
  Serial.print(inNum);

  // find cable using outNum and inNum (or just use polymod3 method, which is faster)
  unsigned int i;
  for(i=0; i<MAX_CONNECTIONS; i++) {
    if(connections[i].outputSocketNum==outNum && connections[i].inputSocketNum==inNum && connections[i].inUse) {
      connections[i].disconnect();
      if(inNum==0) {
        mainConnection = NULL;
      }
      Serial.print(", connection ");
      Serial.print(i);
    }
  }
  Serial.print("\n");
  calculatePolyStatuses();
}

unsigned int checkNum = 0;
void calculatePolyStatuses() {
  Serial.println("Calculating poly statuses...");
  if(mainConnection != NULL) {
    checkNum = 0;
    resetConnection(*mainConnection);
    while(checkNum < 2) {
      //Serial.print("Check num = ");
      //Serial.println(checkNum);
      checkConnection(*mainConnection);
      checkNum ++;
    }
  } else {
    Serial.println("No connections to calculate");
  }
  //Serial.println("Done with poly stuff");
}

void resetConnection(SocketConnection &c) {
  //Serial.println("Reset connection...");
  c.checkNum = 0;
  c.poly = false;
  c.confirmed = false;
  for(unsigned int i=0; i<8; i++) {
    if(c._src->socketInputs[i] != NULL) {
      int connNum = c._src->socketInputs[i]->connNum;
      if(connNum >= 0) {
        if(connections[connNum].confirmed) {
          resetConnection(connections[connNum]);
        }
      }
    }
  }
}
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

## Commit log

2021-10-07 starting patchbay schematic
    [patchbay8in8out.kicad_pcb, patchbay8in8out.sch]
2021-10-07 schematic progress
    [patchbay8in8out.sch]
2021-10-10 first attempt at arduino patchbay library
    [patchbay8in8out.kicad_pcb, patchbay8in8out.sch]
2021-10-11 updated patchbay schematic with diodes and pulldown resistors
    [patchbay8in8out.sch]
2021-10-15 patchbay code looks nice
    [patchbay8in8out.sch]
2021-10-18 changed teensy pins for prototype, added 4 pots
2021-10-25 fixed the stupid memory leak!
    [polymod4.ino]
2022-01-18 after several hours of annoyance, realised that one line was preventing audioconnections disconnecting properly
    [polymod4.ino, testdisconnection.ino]
2022-01-19 oops worked on two computers and didn't push...
    [testlayout.kicad_pcb, testlayout.sch]
2022-01-21 planning pins for new prototype
2022-01-21 more pin stuff
2022-01-24 started kicad layout for first proper prototype
    [inputgroup.kicad_sch, outputgroup.kicad_sch, patchbay8in8out.kicad_sch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]
2022-01-27 graphics and audio working off same I2C pins
2022-06-15 playing around with electrosmith daisy boards, bit of a mess right now
    [polymod_proto_1.kicad_sch]
2022-06-15 schematic is getting somewhere
    [polymod_proto_1.kicad_sch]
2022-06-20 schematic nearly done
    [polymod_proto_1.kicad_sch]
2022-06-20 pcb layout about to start
    [inputgroup.kicad_sch, outputgroup.kicad_sch, polymod_proto_1.kicad_pcb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]
2022-06-20 layout going well
    [outputgroup.kicad_sch, polymod_proto_1.kicad_pcb, polymod_proto_1.kicad_sch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]
2022-07-07 components pretty much in place
    [outputgroup.kicad_sch, polymod_proto_1.kicad_pcb]
2022-07-07 routing started
    [inputgroup.kicad_sch, polymod_proto_1.kicad_pcb, polymod_proto_1.kicad_sch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]
2022-07-08 routing is HARD
    [inputgroup.kicad_sch, polymod_proto_1.kicad_pcb, polymod_proto_1.kicad_sch]
2022-07-10 better layout/routing
    [inputgroup.kicad_sch, polymod_proto_1.kicad_pcb, polymod_proto_1.kicad_sch]
2022-07-10 ummm less sure this is working well but not awful
    [polymod_proto_1.kicad_pcb]
2022-07-11 about to restart routing again
    [polymod_proto_1.kicad_pcb]
2022-07-11 reposition things for more efficient routing
    [polymod_proto_1.kicad_pcb]
2022-07-11 really shouldn't be committing all these zip backups...
    [polymod_proto_1.kicad_pcb]
2022-07-12 mainly just ground routing now
    [polymod_proto_1.kicad_pcb]
2022-07-13 no drc warnings
    [polymod_proto_1.kicad_pcb]
2022-07-13 added helpful notes
    [polymod_proto_1.kicad_pcb]
2022-07-13 maybe ready for fabrication!
    [polymod_proto_1.kicad_pcb, polymodlogodxf.dxf]
2022-07-18 just kinda messing about, trying to recreate teensy version on daisy
2022-07-20 cad stuff
    [lidcuts.FCStd, lidcuts.svg.dxf, morelidcuts.FCStd]
2022-07-20 faffing with the case
    [morelidcuts.FCStd, morelidcutsedgeonly.FCStd]
2022-07-21 quick thought about reducing pin count
2022-08-04 a sound! the patch cable made a sound!
2022-08-04 kinda redesigned all the classes in a rambling text file
    [polymod.cpp]
2022-08-05 i don't understand pointers and i have made a mess
    [lidcuts.svg.dxf]
2022-08-08 wrote a lot of code, it won't work
    [polymod.cpp]
2022-08-08 okay, the process of setting up modules/sockets is ugly, but it works well
2022-08-10 tidied up socket init nicely, and seems i can store socket pointers in module - win!
2022-08-11 why can't i fix the pin number ordering..?
    [polymod.cpp]
2022-08-11 logical pin numbers!
2022-08-15 semi-drastic rewrite to tidy up the socket/connection system before attempting polyphony again
2022-08-15 broke it in a rush
    [polymod.cpp]
2022-08-17 lots of frustrating messing about today, maybe finally figuring out some issues
    [polymod.cpp]
2022-08-22 largely good midi progress but error if lots of midi events at once..?
    [ins-outs.ods]
2022-08-25 bodged the problem where filter crashed for certain frequency values
2022-08-25 white noise works, mixer works
    [polymod.cpp]
